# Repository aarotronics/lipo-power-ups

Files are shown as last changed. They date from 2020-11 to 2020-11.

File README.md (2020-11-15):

# Lipo Power UPS

DC uninterruptible power supply specially designed for 3D printers. It can be used in both 24V and 12V systems. 
For the recovery battery use a high capacity LiPo or LiIon battery, 6S for 24V and 3S for 12V. High power 
diodes conmutate power from power supply or battery so printer will no turn off even when electrical lines 
goes down. While 3D Printer is powering from power supply, current from battery will be 0A because of diode 
barrier, so it wont be discharged at all.

The time that system can keep the 3D Printer working with battery depends directly on how much power the 3D Printer 
drains itself; and also on the battery size, bigger battery will keep the system working for more time.

LiPo and LiIon batteries will damage if they get down of about 3V per cell, thats why the system has an integrated 
power MOSFET and a voltage sensing circuit that will turn off power from battery if it goes down the security 
voltage of 3V per cell. You may have to print again, but battery will be safe.

# Configuration

System can be used both for 24V and 12V systems. In case you are using 12V system, you will not have to use Q4, D17, 
R6 and C8 components. These components make a basic discrete 12V regulator to get 12V from a 24V system.

For 12V system you will have to close the jumper JP1, but for 24V leave it open!!

For 12V R1 should be 33K and for 24V R1 should be 75K. Make sure you are using precise resistor!! These resistors 
make part of the voltage sensor and measurement will be affected by these resistors.

Schematic

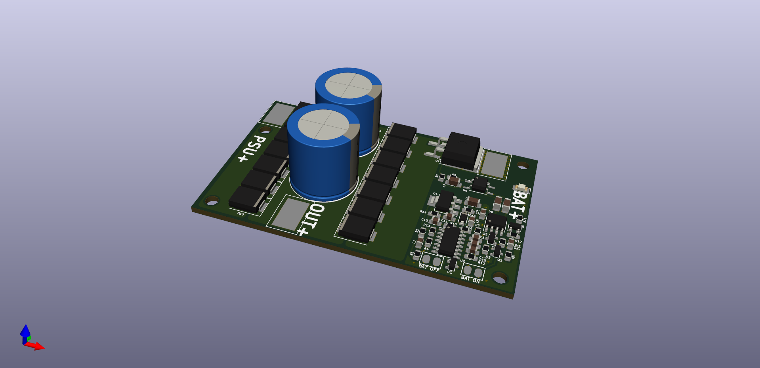
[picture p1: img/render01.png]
3D Render TOP


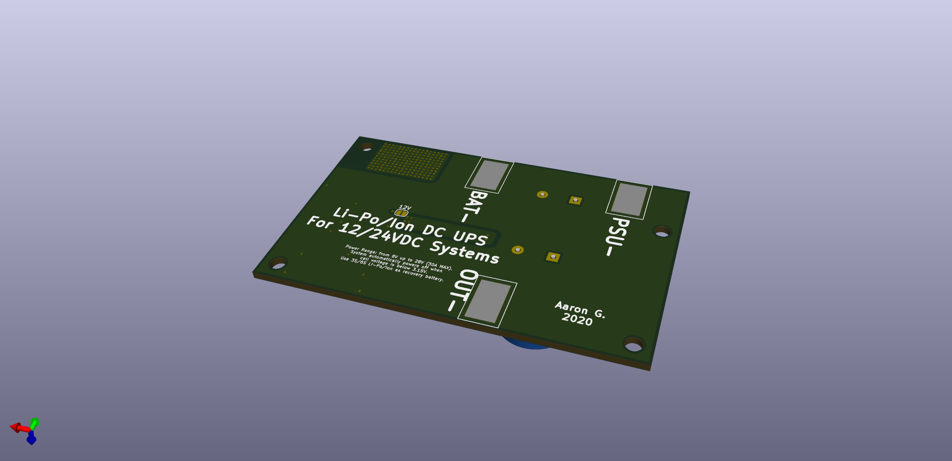
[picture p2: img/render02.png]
3D Render BOT


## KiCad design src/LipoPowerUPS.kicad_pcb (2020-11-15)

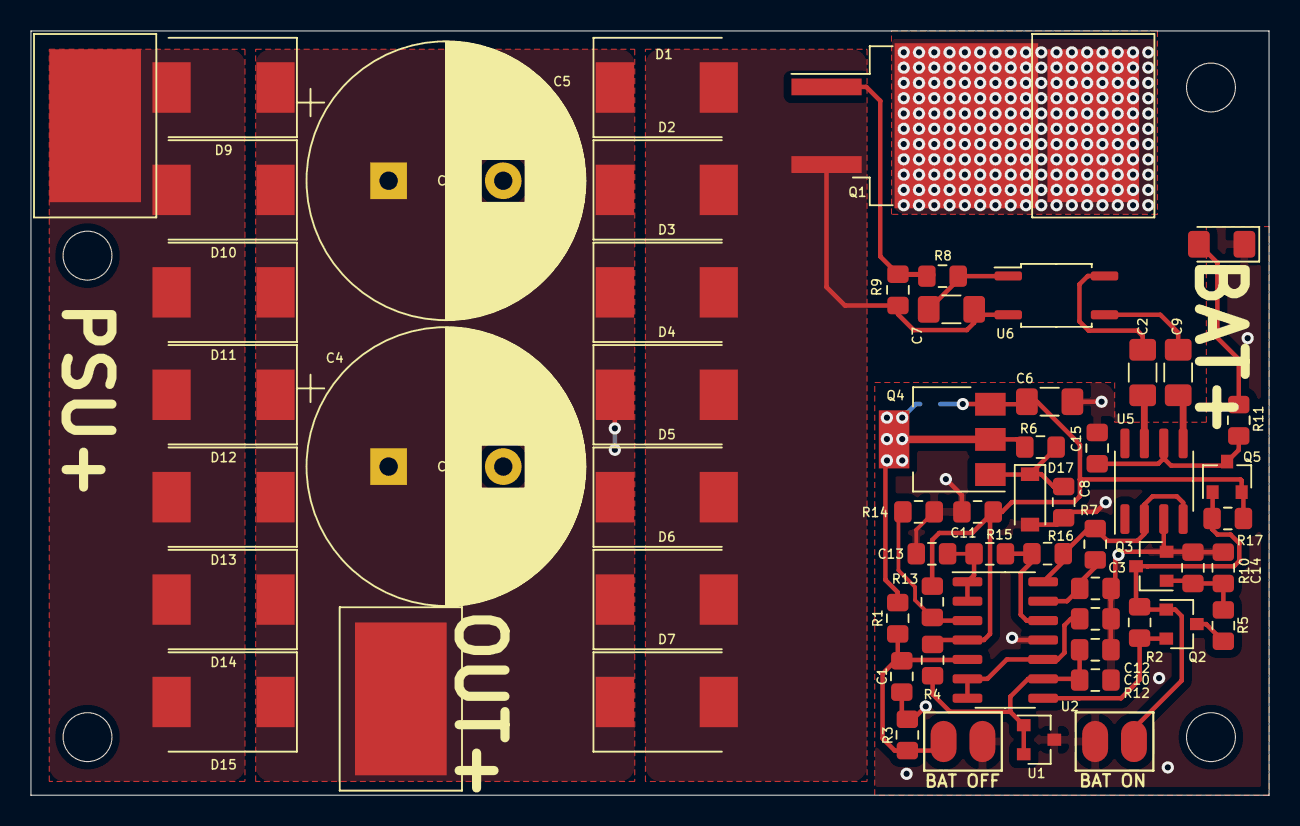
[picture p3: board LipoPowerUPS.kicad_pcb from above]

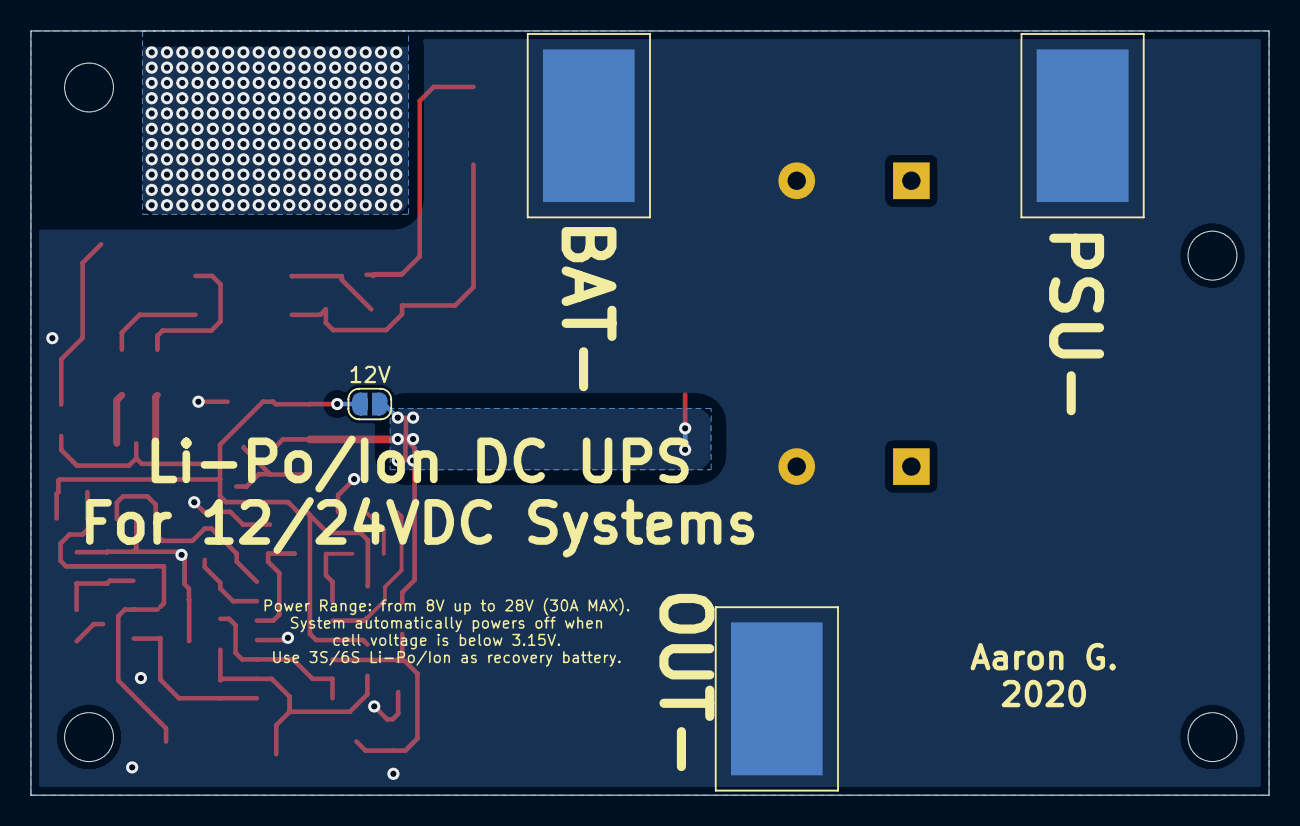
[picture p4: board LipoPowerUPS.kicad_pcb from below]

Board: 2 copper layers, 81.0 x 50.0 mm, 66 parts (4 on the bottom side), 27 nets.

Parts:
C1, C10, C12, C13, C14: 1u; C_0805_2012Metric_Pad1.15x1.40mm_HandSolder
C2, C6, C7, C9: 10u; C_1206_3216Metric_Pad1.42x1.75mm_HandSolder
C3, C8, C11, C15: 100n; C_0805_2012Metric_Pad1.15x1.40mm_HandSolder
C4, C5: 4700u; CP_Radial_D18.0mm_P7.50mm
D1, D2, D3, D4, D5, D6, D7, D9, D10, D11, D12, D13, D14, D15: SS54; D_SMC
D8: BAT ACTIVE; LED_1206_3216Metric_Pad1.42x1.75mm_HandSolder
D17: 12V; D_SOD-123
J1, J2: Battery; AGH_POWER_SMD_PAD
J3, J4: PowerSupply; AGH_POWER_SMD_PAD
J5, J6: OUT; AGH_POWER_SMD_PAD
JP1: 12V; SolderJumper-2_P1.3mm_Open_RoundedPad1.0x1.5mm
Q1: HY4008; TO-263-2
Q2, Q5: AO3401; SOT-23
Q3: AO3400; SOT-23
Q4: BCP56; SOT-223
R1: 120K/51K; R_0805_2012Metric_Pad1.15x1.40mm_HandSolder
R2, R10, R17: 470K; R_0805_2012Metric_Pad1.15x1.40mm_HandSolder
R3: 18K; R_0805_2012Metric_Pad1.15x1.40mm_HandSolder
R4: 3K3; R_0805_2012Metric_Pad1.15x1.40mm_HandSolder
R5: 22K; R_0805_2012Metric_Pad1.15x1.40mm_HandSolder
R6: 680; R_0805_2012Metric_Pad1.15x1.40mm_HandSolder
R7, R16: 2K2; R_0805_2012Metric_Pad1.15x1.40mm_HandSolder
R8: 100; R_0805_2012Metric_Pad1.15x1.40mm_HandSolder
R9: 330K; R_0805_2012Metric_Pad1.15x1.40mm_HandSolder
R11, R15: 1K; R_0805_2012Metric_Pad1.15x1.40mm_HandSolder
R12: 820K; R_0805_2012Metric_Pad1.15x1.40mm_HandSolder
R13, R14: 100K; R_0805_2012Metric_Pad1.15x1.40mm_HandSolder
SW1: BAT ON; AGH_CONN_1X02_2.54mm_SMD
SW2: BAT OFF; AGH_CONN_1X02_2.54mm_SMD
U1: TL431DBZ; SOT-23
U2: LM324; SOIC-14_3.9x8.7mm_P1.27mm
U5: MIC4428; SOIC-8_3.9x4.9mm_P1.27mm
U6: MB1S; SO-4_4.4x3.9mm_P2.54mm

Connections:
+12V: C6.1, C11.1, JP1.2, Q4.3, Q5.2, R4.2, R13.1, R17.1, U2.4
+24V: D9.2, D10.2, D11.2, D12.2, D13.2, D14.2, D15.2, J3.1
+BATT: J1.1, Q1.2
/2V5_REF: C10.1, R4.1, R12.2, U1.1, U1.2, U2.9
/CP1: C2.2, U5.7
/CP2: C9.2, U5.5
/GATE_VCC: C15.2, Q5.3, R11.1, U5.6
/MOSFET_G: Q1.1, R8.1, R9.1
/MOSFET_S: C7.2, D1.2, D2.2, D3.2, D4.2, D5.2, D6.2, D7.2, Q1.3, R9.2, U6.2
GND: C1.2, C3.1, C4.2, C5.2, C6.2, C8.2, C10.2, C11.2, C12.2, C13.1, C14.2, C15.1, D8.1, D17.2, J2.1, J4.1, J6.1, Q3.2, R3.2, R10.1, R12.1, R14.2, SW1.1, SW2.2, U1.3, U2.11, U5.3
unnamed: C1.1, R1.2, R3.1, SW2.1, U2.5
unnamed: C2.1, U6.4
unnamed: C3.2, R7.1, U2.13
unnamed: C7.1, R8.2, U6.1
unnamed: C8.1, D17.1, Q4.1, R6.1
unnamed: C9.1, U6.3
unnamed: C12.1, U2.6, U2.7, U2.10
unnamed: C13.2, R15.2, U2.1, U2.2
unnamed: C14.1, Q3.1, R5.1, R10.2
unnamed: D8.2, R11.2
unnamed: Q2.1, Q3.3, Q5.1, R2.2, R17.2, SW1.2
unnamed: Q2.2, R2.1, U2.8
unnamed: Q2.3, R5.2
unnamed: R13.2, R14.1, U2.3
unnamed: R15.1, R16.2, U2.12
unnamed: R7.2, R16.1, U2.14, U5.2, U5.4
VCC: C4.1, C5.1, D1.1, D2.1, D3.1, D4.1, D5.1, D6.1, D7.1, D9.1, D10.1, D11.1, D12.1, D13.1, D14.1, D15.1, J5.1, JP1.1, Q4.2, Q4.4, R1.1, R6.2

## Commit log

2020-03-02 Added files to repo
    [LipoPowerUPS.kicad_pcb, LipoPowerUPS.sch]
2020-11-15 Upload version V2.0
    [LipoPowerUPS.kicad_pcb, LipoPowerUPS.sch]
